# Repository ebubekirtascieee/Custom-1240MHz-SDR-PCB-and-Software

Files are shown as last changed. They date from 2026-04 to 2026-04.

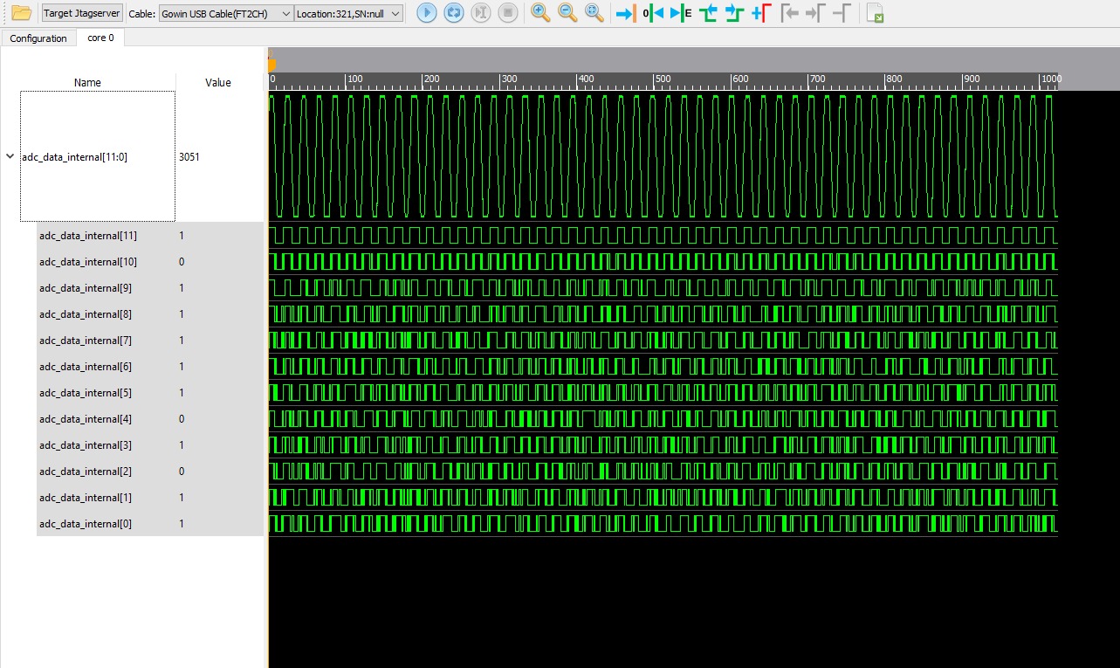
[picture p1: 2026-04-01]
Simulations and Measurements/ADC_test.png

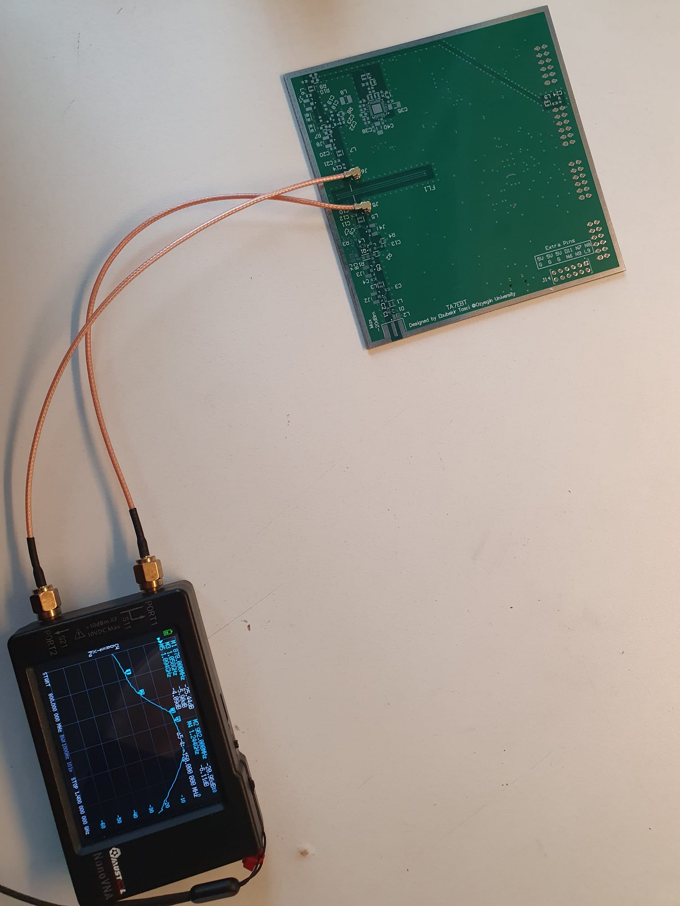
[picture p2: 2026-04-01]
Simulations and Measurements/Microstript-filter-S21.png

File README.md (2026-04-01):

# Custom-1240MHz-SDR-PCB-and-Software
Dual-mode (AM/FM) Software Defined Radio entirely from scratch on a Gowin Tang Primer 20K FPGA!

Front
Back

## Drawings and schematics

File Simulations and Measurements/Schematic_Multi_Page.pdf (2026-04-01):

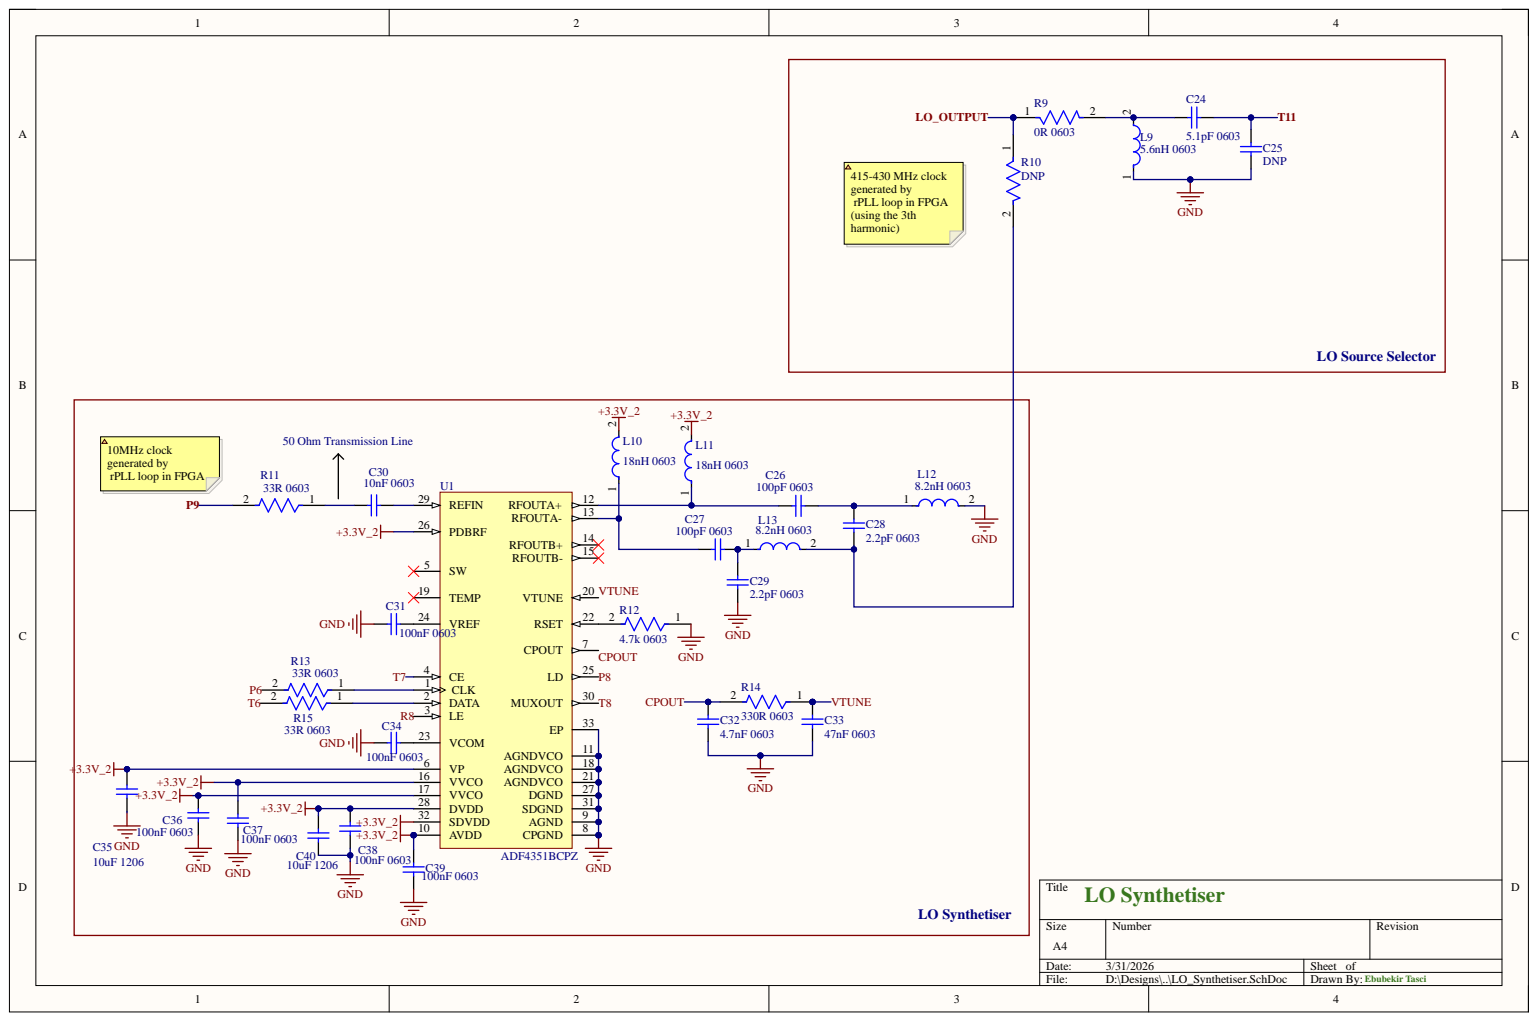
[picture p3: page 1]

415-430 MHz clock
generated by
rPLL loop in FPGA
(using the 3th
harmonic)

10MHz clock

VVCO 17

SDVDD 32

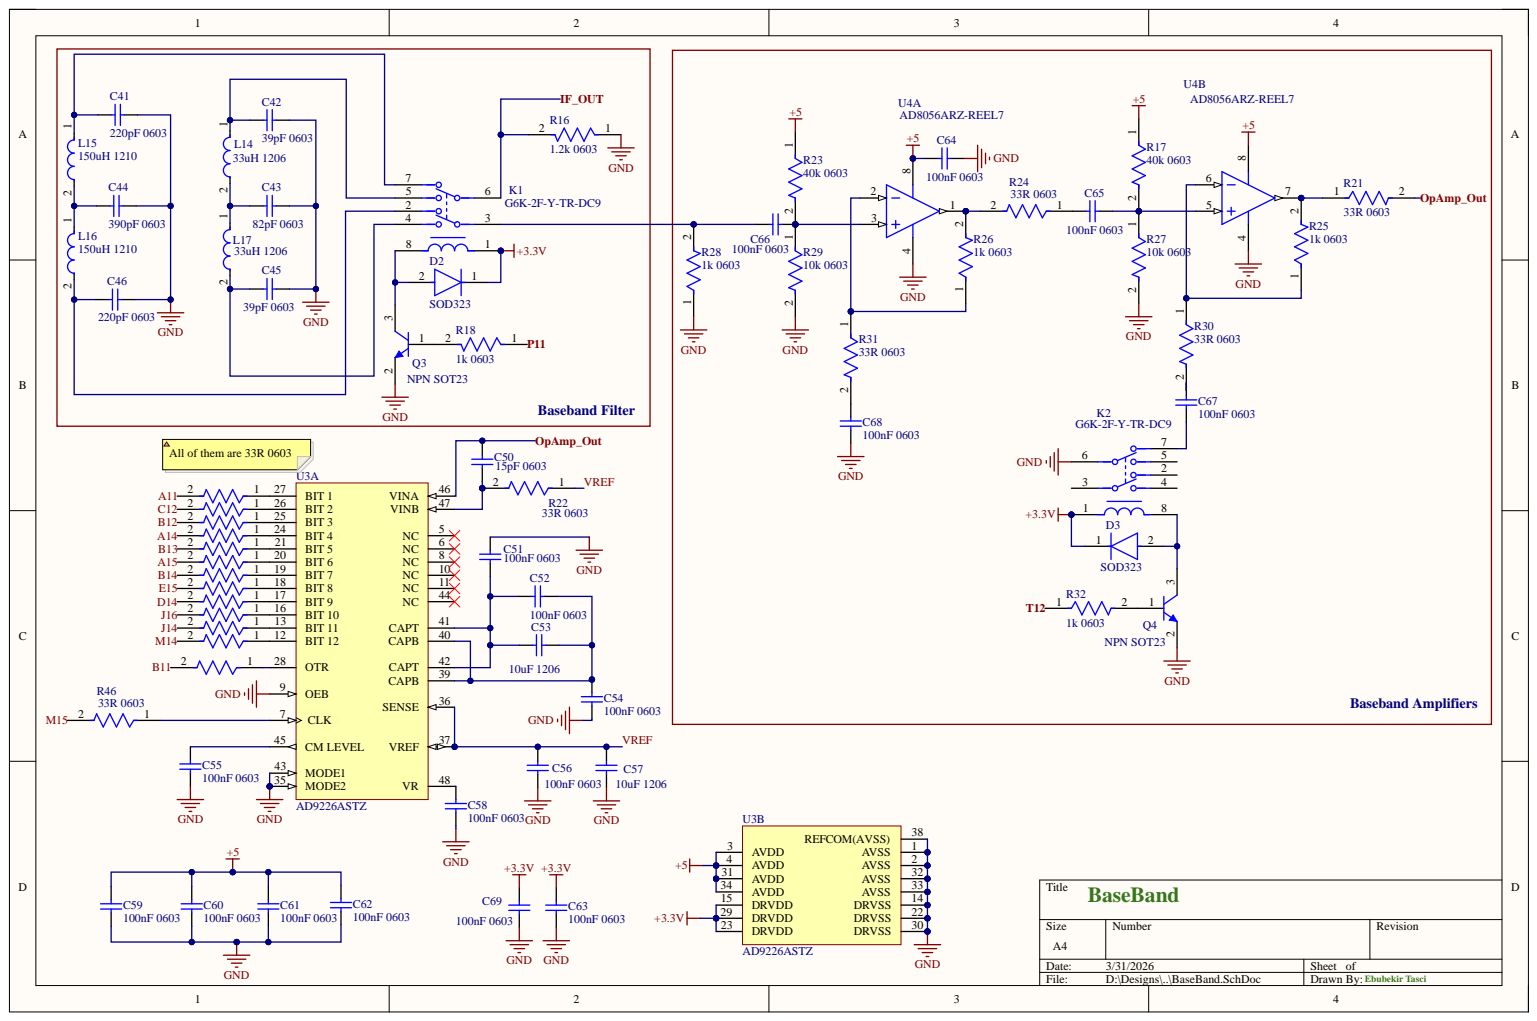
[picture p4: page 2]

U4B AD8056ARZ-REEL7

All of them are 33R 0603

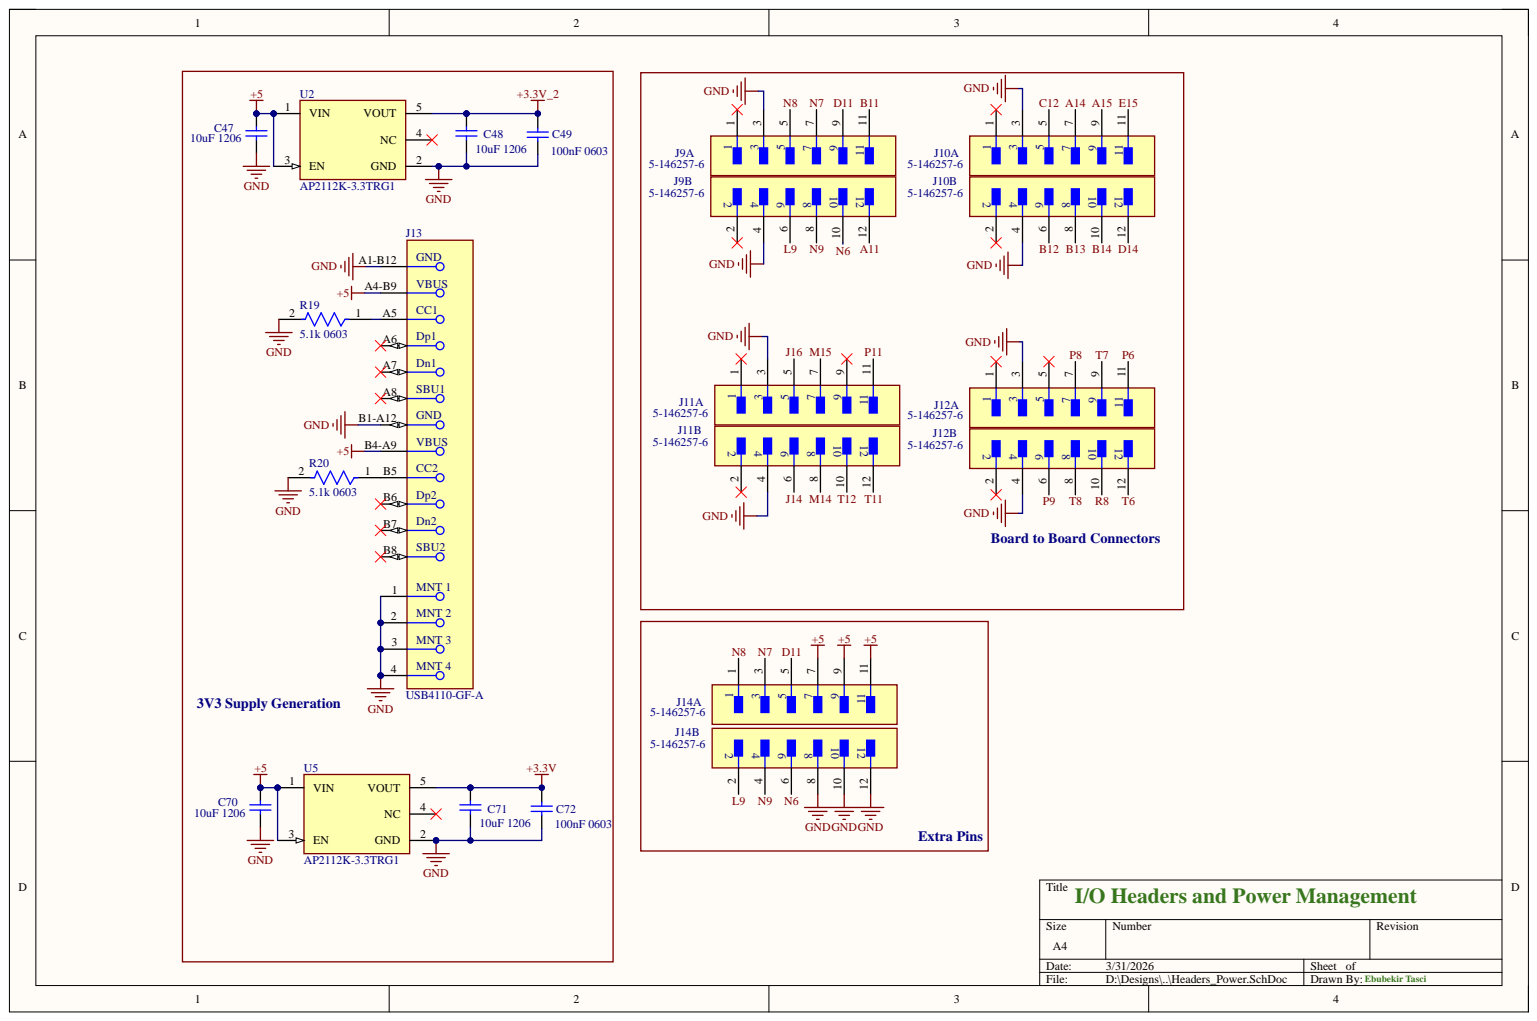
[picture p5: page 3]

GND
Board to Board Connectors

Title
I/O Headers and Power Management

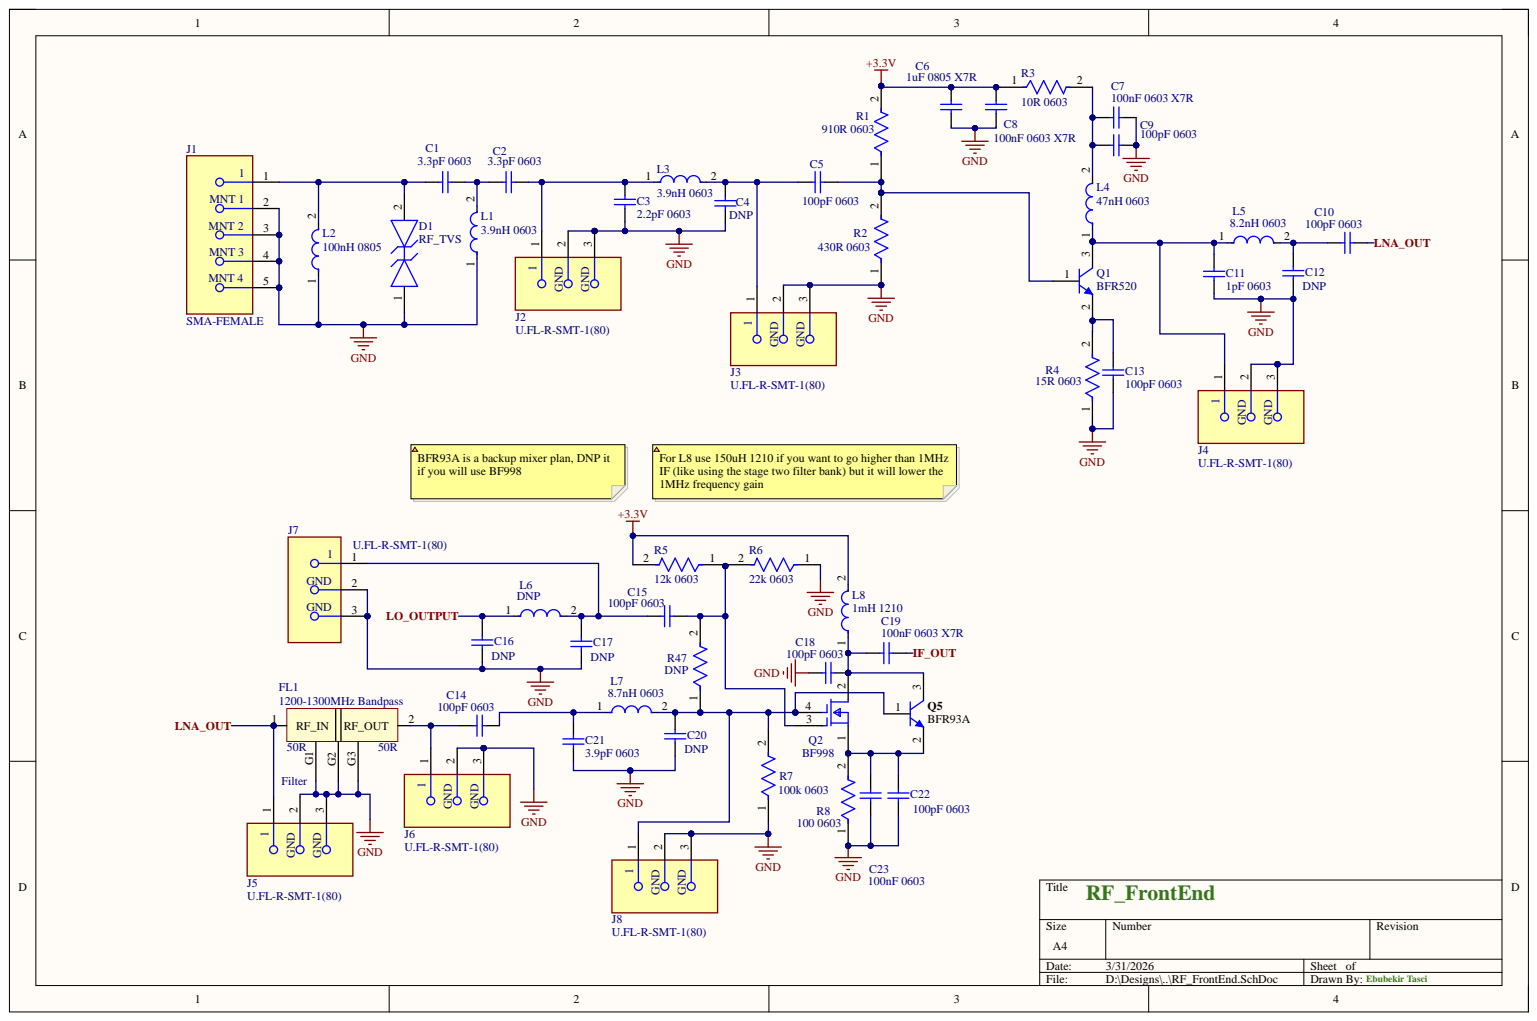
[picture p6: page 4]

BFR93A is a backup mixer plan, DNP it
if you will use BF998

For L8 use 150uH 1210 if you want to go higher than 1MHz
IF (like using the stage two filter bank) but it will lower the
1MHz frequency gain

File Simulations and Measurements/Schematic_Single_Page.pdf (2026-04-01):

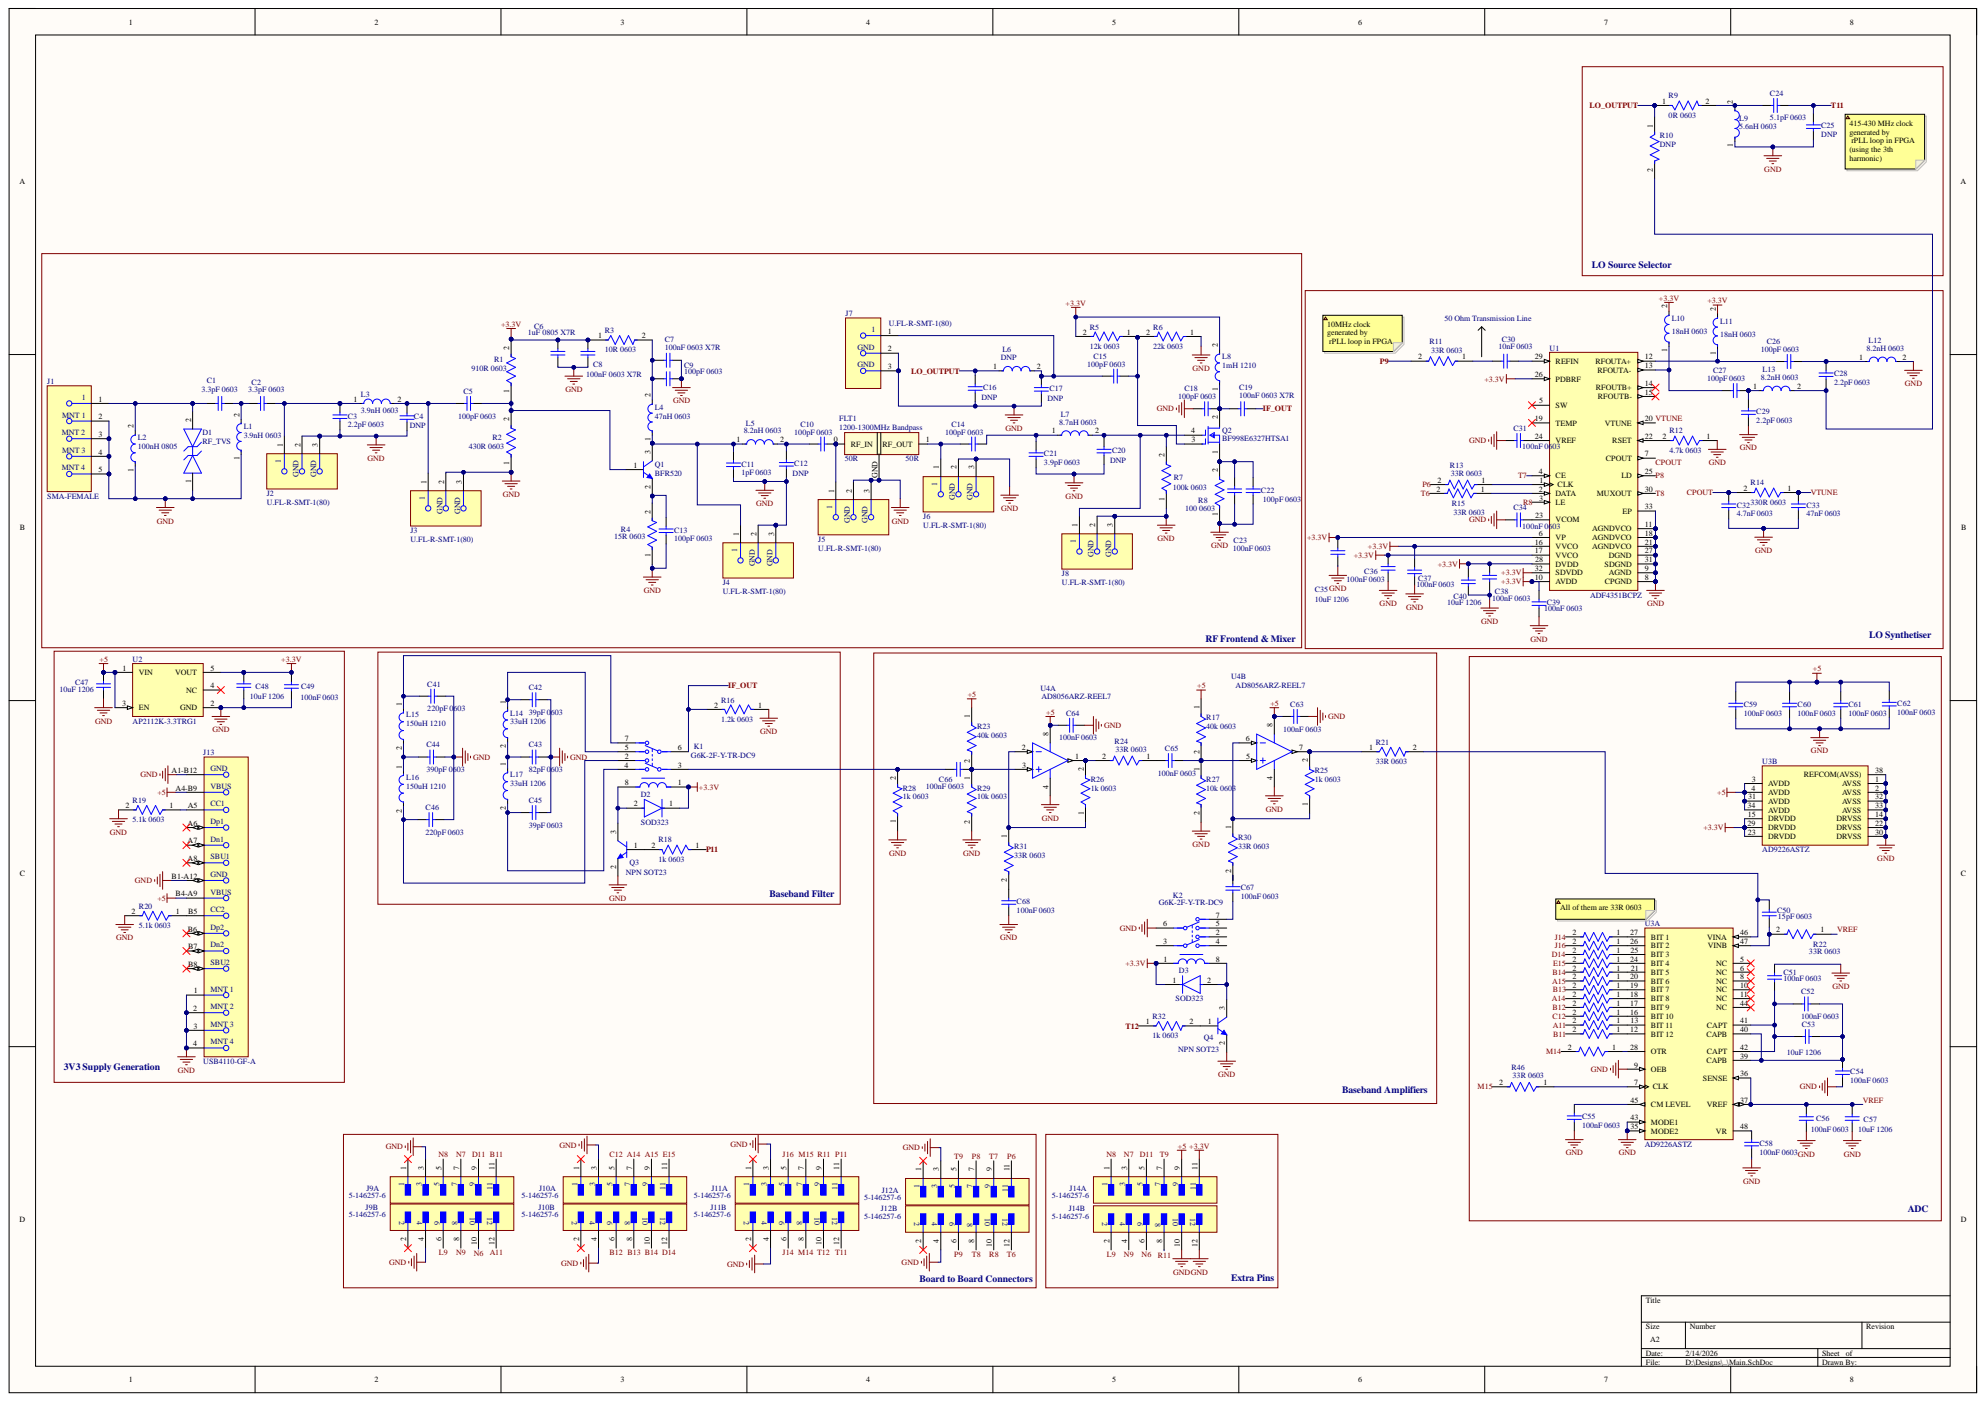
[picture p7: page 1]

415-430 MHz clock
generated by
rPLL loop in FPGA
(using the 3th
harmonic)

10MHz clock

+5 U2 +3.3V | U4B +5 AD8056ARZ-REEL7 +5 | +5

All of them are 33R 0603

Board to Board Connectors

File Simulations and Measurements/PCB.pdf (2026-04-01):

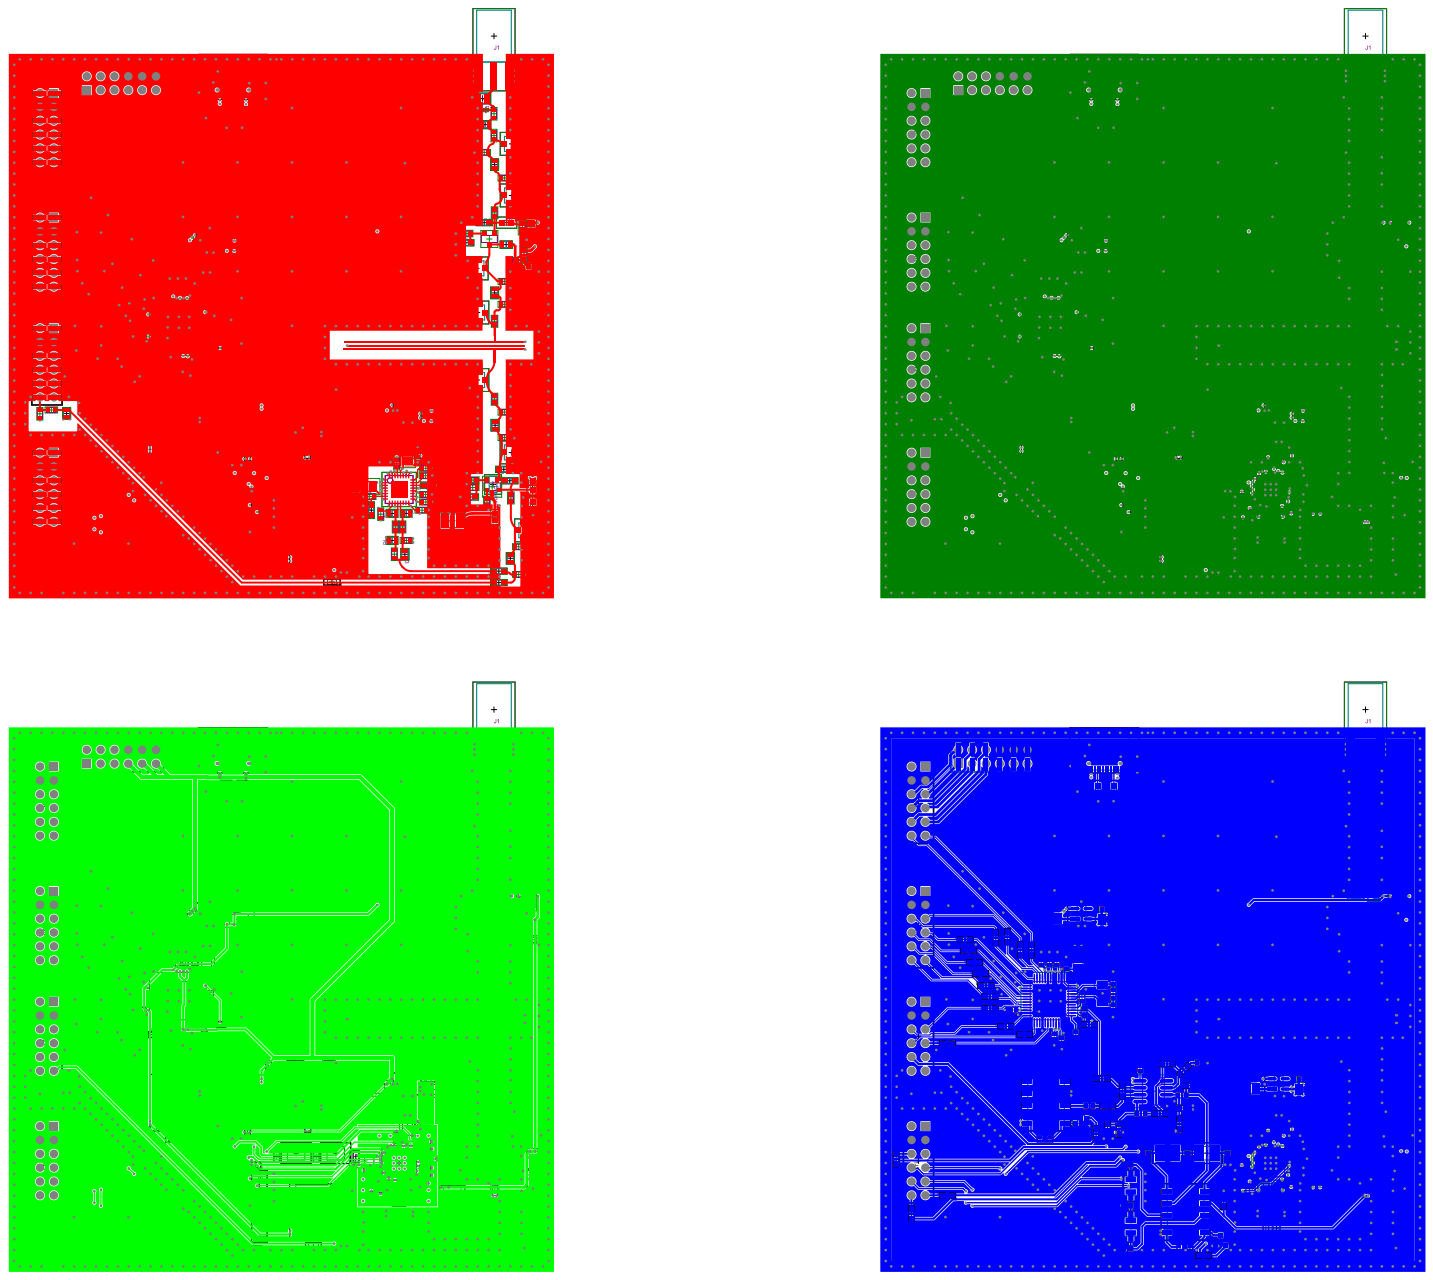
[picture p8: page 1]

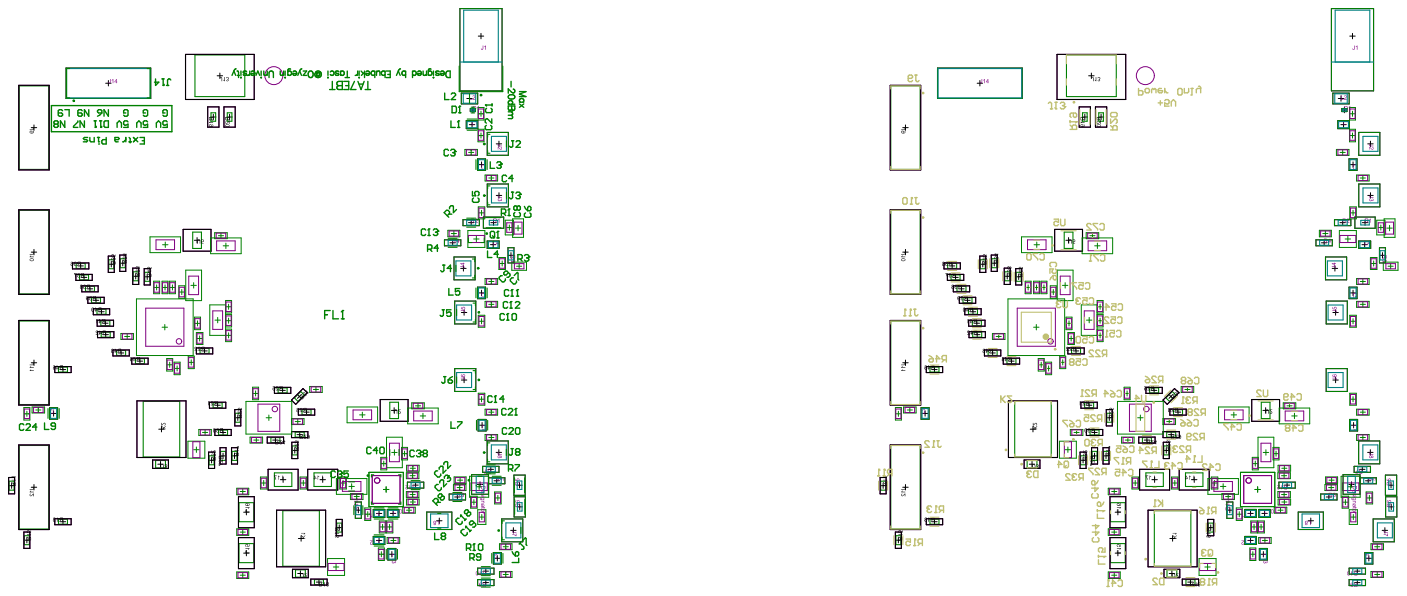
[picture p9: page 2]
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

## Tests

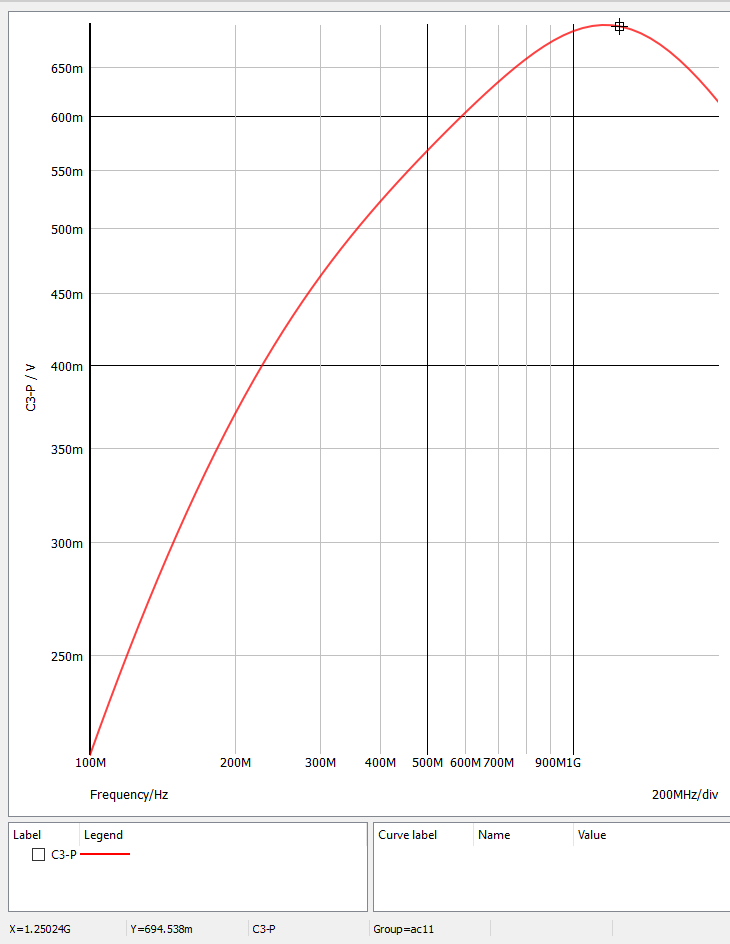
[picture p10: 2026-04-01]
Simulations and Measurements/ADF4351_Output_Balun.png

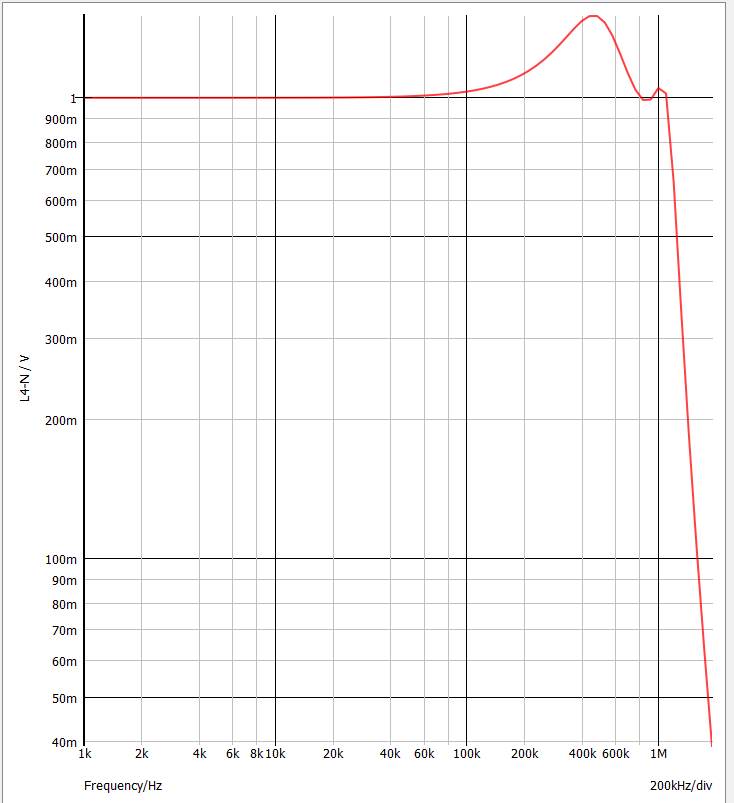
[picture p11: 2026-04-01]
Simulations and Measurements/Filter-Response.png

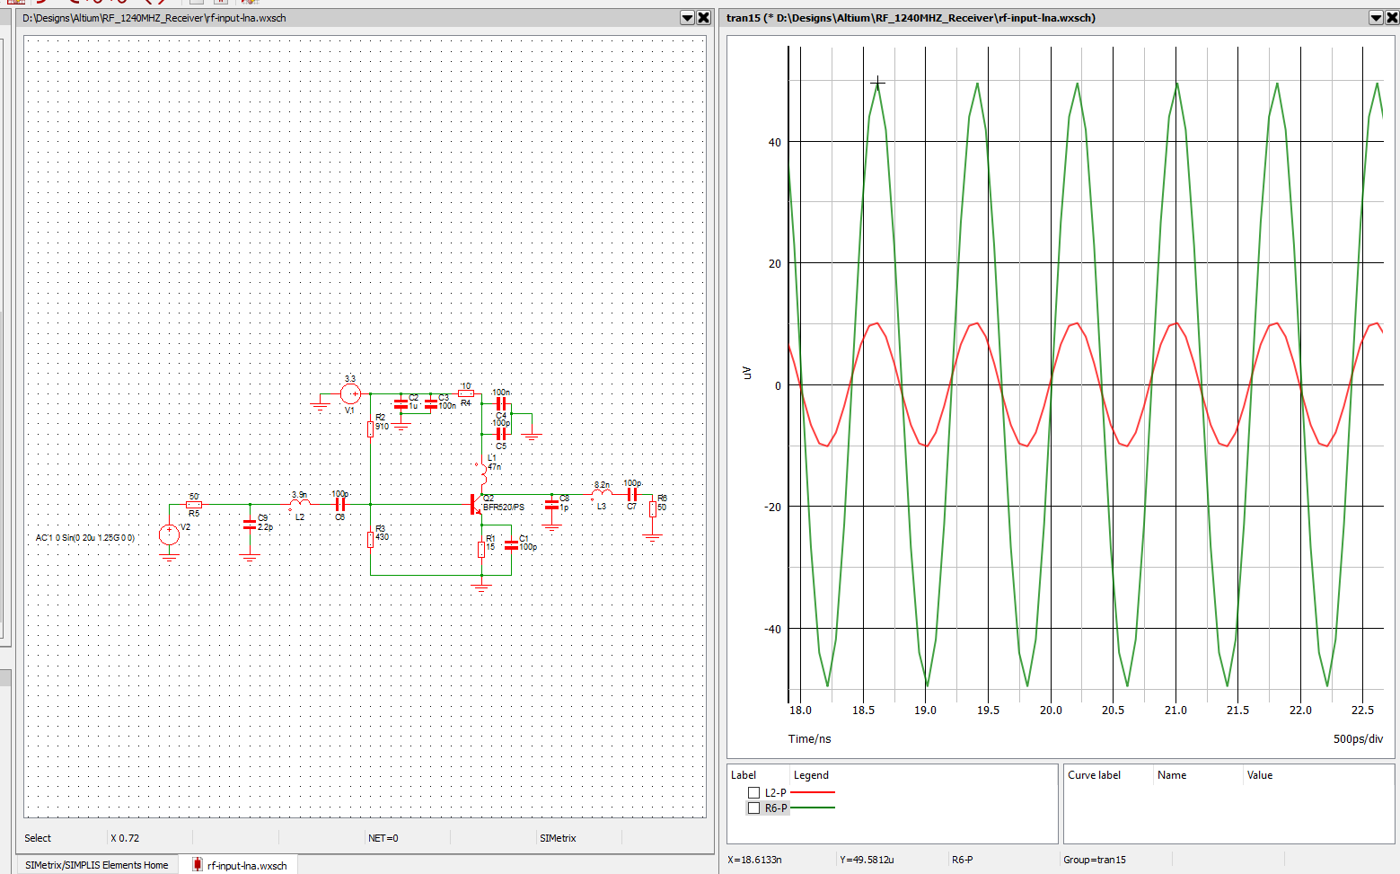
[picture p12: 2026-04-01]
Simulations and Measurements/LNA-Gain.png

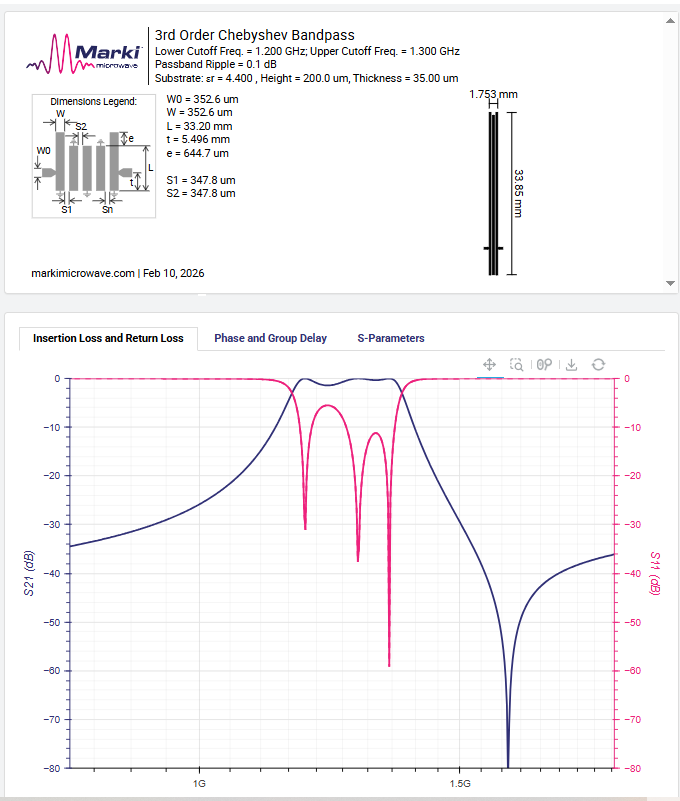
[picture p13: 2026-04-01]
Simulations and Measurements/Microstrip-filter.png

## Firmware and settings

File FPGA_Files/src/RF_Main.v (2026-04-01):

module RF_main(
    input wire sys_clk,           // 27 MHz System Clock (H11)
    input sys_rst_n, 

    // --- ADC Interface (Bank 0) ---
    input wire [11:0] adc_data,   // ADC Parallel Data
    input wire adc_otr,           // ADC Over-Range
    output wire adc_clk_out,      // Clock to ADC

    // --- ADF4351 SPI & Control (Bank 1) ---
    output wire adf_clk,          // SPI Clock (P6)
    output wire adf_data,         // SPI MOSI (T6)
    output wire adf_le,           // Load Enable (R8)
    output wire adf_ce,           // Chip Enable (T7)
    input wire adf_mux,           // Mux Out / Ready (T8)
    input wire adf_ld,            // Lock Detect (P8)

    // --- System Control (Bank 1) ---
    output wire ref_10m_out,        // 10 MHz Reference (P9)
    output wire relay_filter,       // 1 = 5MHz bandwidth, 0 = 1MHz bandwidth
    output reg relay_gain = 1'b0,   // 1 = x33 voltage gain, 0 = x100 voltage gain

    // --- LO Output ---
    output wire LO_OUT,            // 414 MHz Output (T11)
    
    // --- UART ---
    output TX,
    
    //--- Audio Controller ---
    output wire BCK,
    output wire DOUT,
    output wire WS, 
    output wire PA_EN,

    //--- Control Inputs ---
    input S1,   // T3 Change demodulation mode
    input S2,   // T2 Increase center freq.
    input S3,   // D7 Decrease center freq.
    input S4    // C7 Change analog bandwidth 
);

// Default Control States
assign adf_clk = 1'b0;
assign adf_data = 1'b0;
assign adf_le = 1'b0;
assign adf_ce = 1'b0;
assign ref_10m_out = 1'b0; 

// --- 1. LO PLL Instantiation ---
wire lo_lock;
Gowin_rPLL LO_414MHZ(
    .clkout(LO_OUT),   
    .clkin(sys_clk),
    .lock(lo_lock)    
);

// --- 2. Sampling PLL Instantiation ---
wire sampling_lock;
wire clk_20mhz;
Gowin_rPLL_sampling SAMPLING_20MHZ(
    .clkout(clk_20mhz),
    .clkin(sys_clk),          
    .lock(sampling_lock)   
);
assign adc_clk_out = clk_20mhz;

// ==============================================================================
// 1. UART CONTROLLER (Moved to 20.25 MHz Domain)
// ==============================================================================

wire uart_write_done;
reg [7:0] uart_data = 8'b0;
reg uart_wr_en = 1'b0;

UART_Controller #(
    .BAUD_RATE(921_600),
    .CLOCK_FREQ(20_250_000) 
) debug_uart (
    .sys_clk(clk_20mhz),    
    .sys_rst_n(sys_rst_n),
    .write_enable(uart_wr_en), 
    .data_to_send(uart_data),  
    .RX(1'b1), 
    .TX(TX),
    .write_done(uart_write_done),
    .read_done(),
    .data_readed()
);

// ==============================================================================
// 2. AUDIO CONTROLLER
// ==============================================================================


Audio_Controller audio_c(
    .sys_clk(sys_clk),      
    .sys_rst_n(sys_rst_n),
    .audio_in(safe_audio_out), // Connect the demodulated audio here
    .BCK(BCK),
    .DOUT(DOUT),
    .WS(WS),
    .PA_EN(PA_EN)
);
  
// ==============================================================================
// 3. Debouncing & Buttons State Machine (Parallel Hz & FCW Tuning)
// ==============================================================================

reg [19:0] debounce_counter = 0;
reg S1_stable = 1, S2_stable = 1, S3_stable = 1, S4_stable = 1;
reg S1_prev = 1, S2_prev = 1, S3_prev = 1, S4_prev = 1;

always @(posedge clk_20mhz or negedge sys_rst_n) begin
    if (!sys_rst_n) begin
        debounce_counter <= 0;
        S1_stable <= 1; S2_stable <= 1; S3_stable <= 1; S4_stable <= 1;
    end else begin
        if (S1 == S1_stable && S2 == S2_stable && S3 == S3_stable && S4 == S4_stable) begin
            debounce_counter <= 0;
        end else begin
            debounce_counter <= debounce_counter + 1;
            if (debounce_counter >= 20'd1_000_000) begin 
                S1_stable <= S1; S2_stable <= S2; S3_stable <= S3; S4_stable <= S4;
                debounce_counter <= 0;
            end
        end
    end
end

wire S1_pressed = (!S1_stable && S1_prev); 
wire S2_pressed = (!S2_stable && S2_prev); 
wire S3_pressed = (!S3_stable && S3_prev); 
wire S4_pressed = (!S4_stable && S4_prev); 

always @(posedge clk_20mhz or negedge sys_rst_n) begin
    if (!sys_rst_n) begin
        S1_prev <= 1; S2_prev <= 1; S3_prev <= 1; S4_prev <= 1;
    end else begin
        S1_prev <= S1_stable; S2_prev <= S2_stable; S3_prev <= S3_stable; S4_prev <= S4_stable;
    end
end

// --- Dual Acceleration Logic ---
reg [25:0] hold_duration = 0; 
reg [20:0] repeat_timer = 0;  
reg auto_step_pulse = 0;

reg [31:0] current_step_hz = 32'd10_000;
reg [31:0] current_step_fcw = 32'd2_120_963;

always @(posedge clk_20mhz or negedge sys_rst_n) begin
    if (!sys_rst_n) begin
        hold_duration <= 0;
        repeat_timer <= 0;
        auto_step_pulse <= 0;
        current_step_hz <= 32'd10_000;
        current_step_fcw <= 32'd2_120_963;
    end else if (!S2_stable || !S3_stable) begin
        if (hold_duration < 26'd40_000_000) hold_duration <= hold_duration + 1;

        if (hold_duration > 26'd30_000_000) begin
            current_step_hz <= 32'd100_000;       
            current_step_fcw <= 32'd21_209_631;   
        end else if (hold_duration > 26'd15_000_000) begin
            current_step_hz <= 32'd50_000;        
            current_step_fcw <= 32'd10_604_815;   
        end else begin
            current_step_hz <= 32'd10_000;        
            current_step_fcw <= 32'd2_120_963;    
        end

        if (hold_duration > 26'd10_000_000) begin
            if (repeat_timer >= 21'd2_000_000) begin 
                repeat_timer <= 0;
                auto_step_pulse <= 1; 
            end else begin
                repeat_timer <= repeat_timer + 1;
                auto_step_pulse <= 0;
            end
        end else begin
            repeat_timer <= 0;
            auto_step_pulse <= 0;
        end
    end else begin
        hold_duration <= 0;
        repeat_timer <= 0;
        auto_step_pulse <= 0;
        current_step_hz <= 32'd10_000;
        current_step_fcw <= 32'd2_120_963;
    end
end

wire S2_action = S2_pressed || (!S2_stable && auto_step_pulse);
wire S3_action = S3_pressed || (!S3_stable && auto_step_pulse);

// --- System State Registers ---
reg mod_type = 1'b0;                     
reg [31:0] center_freq = 32'd1_000_000;     // GUI Display Frequency
reg [31:0] tuning_word = 32'd212_097_150;   // Hardware NCO FCW
reg analog_bandwidth_extended = 1'b0;    

assign relay_filter = analog_bandwidth_extended;
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

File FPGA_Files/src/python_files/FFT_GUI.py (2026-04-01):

import sys
import serial
import threading
import numpy as np
import pyqtgraph as pg
from pyqtgraph.Qt import QtCore, QtWidgets

# ==========================================
# GLOBAL VARIABLES (Cross-Thread Data)
# ==========================================


shared_fft_data = np.zeros(1024, dtype=np.uint16)
shared_freq = 1000000
shared_mod_type = 0
shared_bw = 0
data_lock = threading.Lock()


# ==========================================
# 1. THE DATA MINER (Background USB Thread)
# ==========================================
def serial_thread():
    global shared_fft_data, shared_freq, shared_mod_type, shared_bw

    # --- CHANGE 'COM6' TO YOUR ACTUAL TANG PRIMER PORT ---
    PORT = 'COM6'
    BAUD = 921600

    try:
        ser = serial.Serial(PORT, BAUD, timeout=1)
        print(f"Connected to FPGA on {PORT}!")
    except Exception as e:
        print(f"Failed to open port: {e}")
        return

    while True:
        try:
            # Hunt for the Sync Header: 0xAA 0x55
            if ser.read(1) == b'\xAA':
                if ser.read(1) == b'\x55':

                    # 5 bytes header + (1024 bins * 2 bytes) = 2053 total bytes
                    payload = ser.read(2053)

                    if len(payload) == 2053:
                        flags = payload[0]
                        mod_type = flags & 0x01
                        bw_extended = (flags >> 1) & 0x01

                        center_freq = (payload[1] << 24) | (payload[2] << 16) | \
                                      (payload[3] << 8) | payload[4]

                        # Unpack as Big-Endian 16-bit integers (>u2)
                        fft_bins = np.frombuffer(payload[5:], dtype=np.dtype('>u2'))

                        with data_lock:
                            np.copyto(shared_fft_data, fft_bins)
                            shared_freq = center_freq
                            shared_mod_type = mod_type
                            shared_bw = bw_extended

        except Exception as e:
            print(f"Serial Error: {e}")
            break


# ==========================================
# 2. THE PAINTER (GUI Thread)
# ==========================================

class SDRWindow(QtWidgets.QMainWindow):
    def __init__(self):
        super().__init__()
        self.setWindowTitle("Tang Primer 20K SDR - Professional Spectrum Analyzer")
        self.resize(1100, 700)

        main_widget = QtWidgets.QWidget()
        self.setCentralWidget(main_widget)
        layout = QtWidgets.QVBoxLayout(main_widget)

        self.info_label = QtWidgets.QLabel("Connecting to FPGA...")
        self.info_label.setStyleSheet(
            "font-family: 'Consolas', monospace; font-size: 22px; "
            "font-weight: bold; color: #00FF00; background-color: #111; "
            "padding: 15px; border: 2px solid #333; border-radius: 5px;"
        )
        layout.addWidget(self.info_label)

        self.plot_widget = pg.PlotWidget()
        self.plot_widget.setBackground('k')
        self.plot_widget.showGrid(x=True, y=True, alpha=0.4)

        # UPGRADE: Set Y-axis to -100 dBFS for 16-bit dynamic range
        self.plot_widget.setYRange(-100, 5, padding=0)
        self.plot_widget.setLabel('left', 'Amplitude', units='dBFS')
        self.plot_widget.setLabel('bottom', 'Frequency', units='MHz')
        layout.addWidget(self.plot_widget)

        self.curve = self.plot_widget.plot(pen=pg.mkPen('y', width=2))

        # --- Tuned Frequency Marker ---
        tune_pen = pg.mkPen(color=(255, 50, 50, 180), width=3)
        self.tune_line = pg.InfiniteLine(angle=90, movable=False, pen=tune_pen)
        self.plot_widget.addItem(self.tune_line)

        # --- Video Filter (EMA) Variables ---
        # Initialize at new noise floor (-100 dB)
        self.smooth_fft = np.full(512, -100.0)
        self.alpha = 0.3

        self.timer = QtCore.QTimer()
        self.timer.timeout.connect(self.update_gui)
        self.timer.start(33)

    def update_gui(self):
        with data_lock:
            local_fft = np.copy(shared_fft_data)
            local_freq = shared_freq
            local_mod = shared_mod_type
            local_bw = shared_bw

        raw_bins = local_fft[:512].astype(float)

        # se 65535.0 as the 16-bit full-scale reference
        raw_bins[raw_bins < 1] = 1
        dbfs_raw = 20 * np.log10(raw_bins / 65535.0)

        # VIDEO FILTER
        self.smooth_fft = (dbfs_raw * self.alpha) + (self.smooth_fft * (1.0 - self.alpha))

        # RF MAPPING
        LO_MHZ = 1242.0
        freq_x_axis = np.linspace(LO_MHZ, LO_MHZ + 10.125, 512)

        # Draw the curve
        self.curve.setData(freq_x_axis, self.smooth_fft)

        # Zoom Logic
        if local_bw == 1:
            self.plot_widget.setXRange(LO_MHZ, LO_MHZ + 5.0, padding=0)
        else:
            self.plot_widget.setXRange(LO_MHZ, LO_MHZ + 1.0, padding=0)

        # Update text
        mode_str = "FM" if local_mod == 1 else "AM"
        bw_str = "5 MHz" if local_bw == 1 else "1 MHz"
        tuned_freq = LO_MHZ + (local_freq / 1e6)

        self.info_label.setText(
            f"TUNED RF: {tuned_freq:.3f} MHz | MODE: {mode_str} | BW: {bw_str}"
        )

        # Snap red marker to frequency
        self.tune_line.setValue(tuned_freq)


# ==========================================
# EXECUTION ENTRY POINT
# ==========================================
if __name__ == '__main__':
    t = threading.Thread(target=serial_thread, daemon=True)
    t.start()

    app = QtWidgets.QApplication(sys.argv)
    window = SDRWindow()
    window.show()
    sys.exit(app.exec())
